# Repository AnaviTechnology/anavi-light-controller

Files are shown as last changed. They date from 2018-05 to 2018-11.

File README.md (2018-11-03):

# ANAVI Light Controller

ANAVI Light Controller is an open source hardware board for controlling 12V RGB LED strip powered by free and open source software. It features:

* Slot for RGB LED strip
* 12V input for the RGB LED strip
* Slots for up to 3 plug and play I2C sensors for temperature, barometric pressure, humidity and light
* UART (Universal asynchronous receiver/transmitter) pins for debugging

Open source software for ANAVI Light Controller written as an Arduino sketch is also available at [GitHub](https://github.com/AnaviTechnology/anavi-light-controller-sw).

# License

The project is released under the [Creative Commons Attribution-ShareAlike 4.0 International (CC BY-SA 4.0)](https://creativecommons.org/licenses/by-sa/4.0/).

Note: This is a human-readable summary of (and not a substitute for) the [license](https://creativecommons.org/licenses/by-sa/4.0/legalcode).

You are free to:

Share — copy and redistribute the material in any medium or format Adapt — remix, transform, and build upon the material for any purpose, even commercially. The licensor cannot revoke these freedoms as long as you follow the license terms. Under the following terms:

Attribution — You must give appropriate credit, provide a link to the license, and indicate if changes were made. You may do so in any reasonable manner, but not in any way that suggests the licensor endorses you or your use. ShareAlike — If you remix, transform, or build upon the material, you must distribute your contributions under the same license as the original. No additional restrictions — You may not apply legal terms or technological measures that legally restrict others from doing anything the license permits. Notices:

You do not have to comply with the license for elements of the material in the public domain or where your use is permitted by an applicable exception or limitation. No warranties are given. The license may not give you all of the permissions necessary for your intended use. For example, other rights such as publicity, privacy, or moral rights may limit how you use the material.

You will have to provide a link to the original creator of the project http://www.anavi.technology on any documentation or website.

Credit can be attributed through a link to the creator website: http://www.anavi.technology

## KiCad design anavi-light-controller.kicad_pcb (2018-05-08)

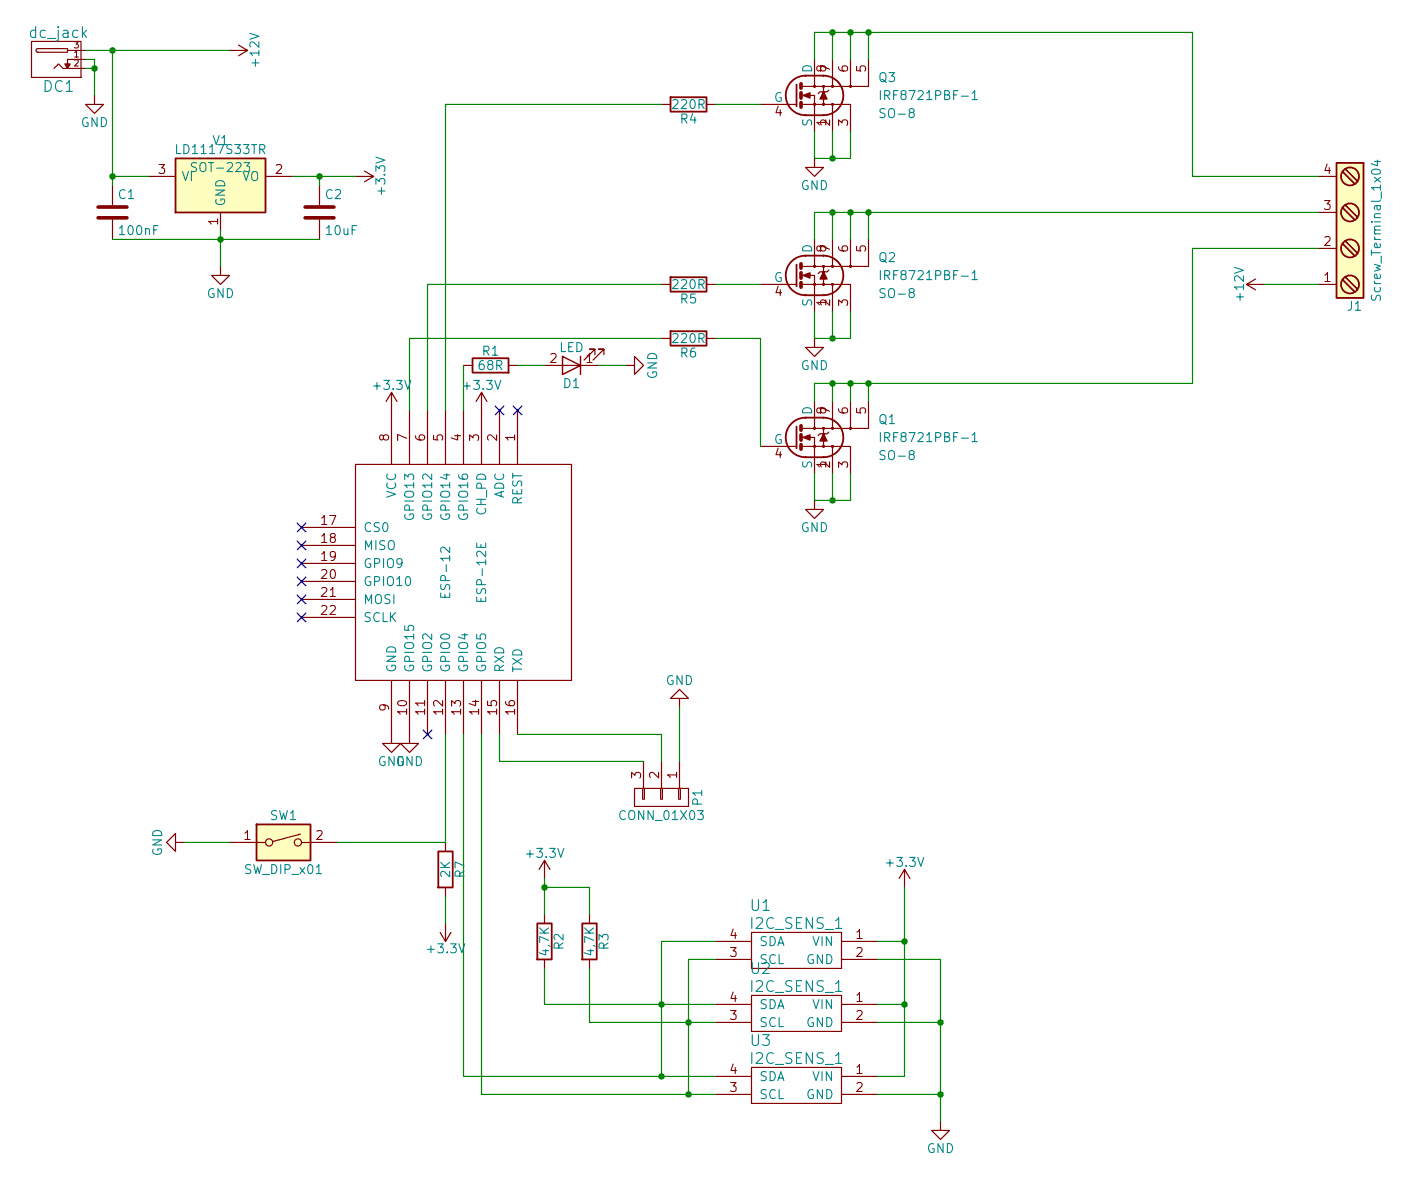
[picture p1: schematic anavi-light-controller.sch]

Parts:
C1: 100nF; C_0603_HandSoldering
C2: 10uF; C_0805_HandSoldering
D1: LED; LED_1206
DC1: dc_jack; dc_socket
ESP-12: ESP-12E; ESP-12E_SMD
J1: Screw_Terminal_1x04; TerminalBlock_Pheonix_MKDS1.5-4pol
P1: CONN_01X03; Pin_Header_Straight_1x03
Q1, Q2, Q3: IRF8721PBF-1; SO-8
R1: 68R; R_0603_HandSoldering
R2, R3: 4,7K; R_0603_HandSoldering
R4, R5, R6: 220R; R_0603_HandSoldering
R7: 2K; C_0603_HandSoldering
SW1: SW_DIP_x01; SW_PUSH_6mm_h4.3mm
U1, U2, U3: I2C_SENS_1; Pin_Header_Straight_1x04
V1: LD1117S33TR; SOT-223

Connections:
+3V3: C2.1, ESP-12.3 (CH_PD), ESP-12.8 (VCC), R2.1, R3.1, R7.2, U1.1 (VIN), U2.1 (VIN), U3.1 (VIN), V1.2 (VO)
+12V: C1.1, DC1.3, J1.1, V1.3 (VI)
GND: C1.2, C2.2, D1.1 (K), DC1.1, DC1.2, ESP-12.9 (GND), ESP-12.10 (GPIO15), P1.1, Q1.1 (S), Q1.2, Q1.3, Q2.1 (S), Q2.2, Q2.3, Q3.1 (S), Q3.2, Q3.3, SW1.1, U1.2 (GND), U2.2 (GND), U3.2 (GND), V1.1 (GND)
unnamed: D1.2 (A), R1.2
unnamed: ESP-12.4 (GPIO16), R1.1
unnamed: ESP-12.5 (GPIO14), R4.2
unnamed: ESP-12.6 (GPIO12), R5.2
unnamed: ESP-12.7 (GPIO13), R6.2
unnamed: ESP-12.12 (GPIO0), R7.1, SW1.2
unnamed: ESP-12.13 (GPIO4), R2.2, U1.4 (SDA), U2.4 (SDA), U3.4 (SDA)
unnamed: ESP-12.14 (GPIO5), R3.2, U1.3 (SCL), U2.3 (SCL), U3.3 (SCL)
unnamed: ESP-12.15 (RXD), P1.3
unnamed: ESP-12.16 (TXD), P1.2
unnamed: J1.2, Q1.5, Q1.6, Q1.7, Q1.8 (D)
unnamed: J1.3, Q2.5, Q2.6, Q2.7, Q2.8 (D)
unnamed: J1.4, Q3.5, Q3.6, Q3.7, Q3.8 (D)
unnamed: Q1.4 (G), R6.1
unnamed: Q2.4 (G), R5.1
unnamed: Q3.4 (G), R4.1

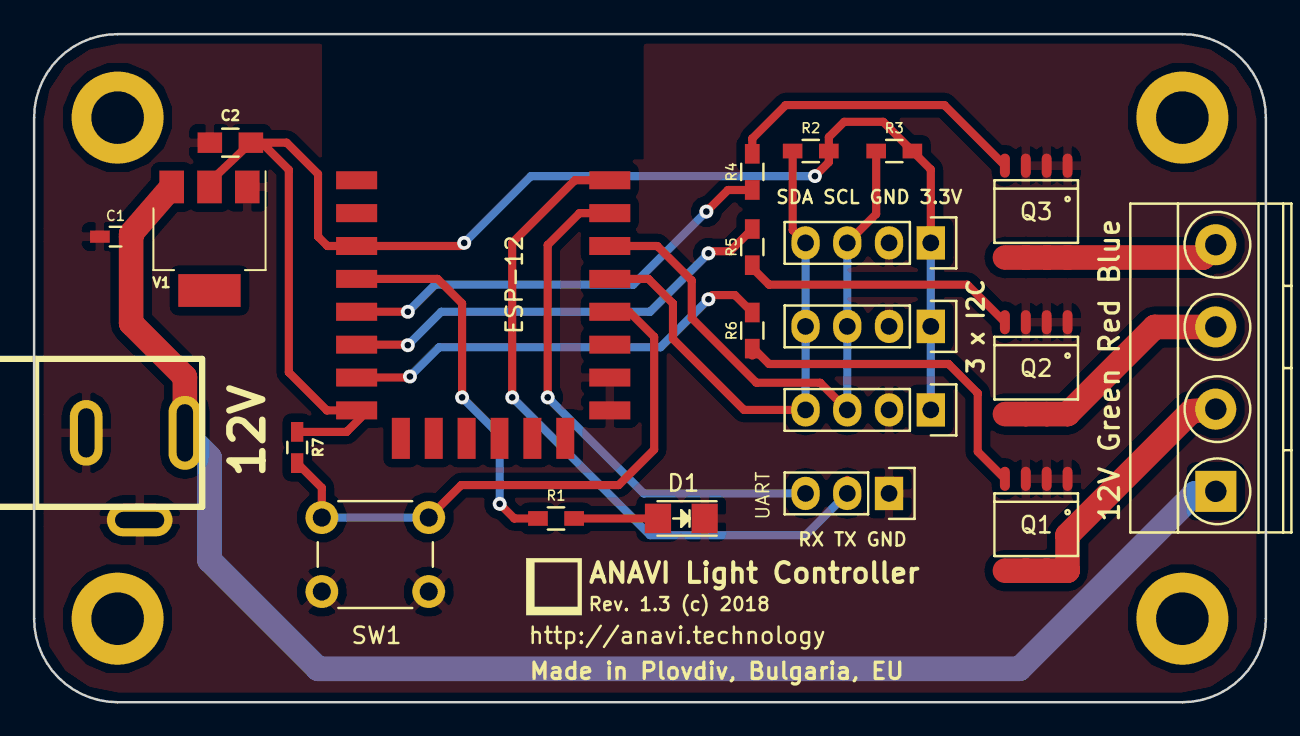
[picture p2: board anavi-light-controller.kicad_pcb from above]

Board: 2 copper layers, 74.9 x 40.6 mm, 22 parts (0 on the bottom side), 19 nets.

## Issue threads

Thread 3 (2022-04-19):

Temperature and humidity sensors stopped working

mircicd, 2022-04-19:
Hello

I did not find any official support channels so I'm putting my (most likely user-)issue here: I have been using the Light Controller for a good amount of time now without any problems. I've hooked up a few additional sensors to track temperature, humidity and light intensity: HTU21D, BH1750 and SHT31 (for which I have added support myself). All the sensors have worked flawlessly for more than a year.

I'm running the Light Controller in a Home Assistant Setup. The problem is that all of a sudden I stopped getting sensor data into my MQTT broker, for any of the sensors. I can still send commands to the Light Controller to control the lights, but it just won't send any sensor data. Of course I did several resets and flashed the original firmware but without success.

Is this a known issue or is there any way to debug to find out what the problem might be? I'm using Mosquitto and these are the only relevant logs I could find:
```
Tue Apr 19 18:54:15 2022: New connection from 192.168.1.27 on port 1883.
Tue Apr 19 18:54:15 2022: Client anavi-light-controller-4af09a0ea709ffdc47d2a9fc1cf81f9 has exceeded timeout, disconnecting.
Tue Apr 19 18:54:15 2022: Socket error on client anavi-light-controller-4af09a0ea709ffdc47d2a9fc1cf81f9, disconnecting.
Tue Apr 19 18:54:15 2022: New client connected from 192.168.1.27 as anavi-light-controller-4af09a0ea709ffdc47d2a9fc1cf81f9 (c1, k15, u'').
```

Any help is appreciated!

leon-anavi, 2022-04-20:
Hi @mircicd,

As an entirely open source project this is an appropriate place to report this type of issues.

Are the sensor modules still properly working as hardware and detected by their I2C addresses?

Have you tried flashing the latest version of original open source firmware?

Would you like to contribute your modifications for SHT31-D as a GitHub pull request to https://github.com/AnaviTechnology/anavi-light-controller-sw ?

Best regards,
Leon

mircicd, 2022-05-13:
Hi Leon

As per your suggestion I took out the sensors and tested them individually and one by one on a different device. Turned out that the SHT31 sensor was broken! And for some strange reason, leaving it connected to the Light Controller causes all sensor data to stop. After having removed only the broken sensor, I now get sensor readings again as expected. Thanks a lot for your push to the right direction.

I will gladly open a pull request to add SHT31-D support once I find some time to clean up and polish my code.

Best regards,
Dejan

Closed 2022-05-13.

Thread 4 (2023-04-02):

Quick question

Fizcko, 2023-04-02:
Hello,

Can this project support a 12v 3A input for a 10m RGB LED strip ?

I don't know if all electronics components can support up to 3A.

Thanks for the reply

leon-anavi, 2023-04-02:
Hi @Fizcko,

ANAVI Light Controller uses IRF8721PBF/IRF8721TRPBF MOSFET for each of the 3 channels for the RGB light. According to the datasheet the Continuous Drain Current of each is up to 14A: https://www.mouser.bg/ProductDetail/Infineon-IR/IRF8721TRPBF

The traces on the boards are 20mils so in practice it is about 2.5Amps per channel and 60mils for the 12V trace. Depending on your setup it is also possible to wire the 12V for the RGB LED strip directory to the power adapter (and skip using the 12V trace on the board). It is also to use a DC barrel jack male adapter to a screw terminal. These adapters are quite popular because they are widely used for CCTV and can be found from many resellers, for example Sparkfun offers them: https://www.sparkfun.com/products/10287

Fizcko, 2023-04-02:
@leon-anavi

I didn't buy anything I'm studying the technical feasibility for the moment.

Thanks for the reply

Closed 2023-04-02.

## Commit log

2017-08-10 anavi-light-controller: Initial version
    [anavi-light-controller.kicad_pcb, anavi-light-controller.sch]
2017-08-10 anavi-light-controller: Add labels
    [anavi-light-controller.kicad_pcb]
2017-08-10 anavi-light-controller.kicad_pcb: Rotate I2C
    [anavi-light-controller.kicad_pcb]
2017-08-10 anavi-light-controller.kicad_pcb: Increase tracks
    Increace 12V tracks and change the positions of
    the capacitors.
    [anavi-light-controller.kicad_pcb]
2017-08-10 anavi-light-controller.kicad_pcb: no vias
    [anavi-light-controller.kicad_pcb]
2017-08-10 anavi-light-controller.kicad_pcb: reduce
    Reduce width of the PCB and change the mounting holes.
    [anavi-light-controller.kicad_pcb]
2017-09-12 Change LDO voltage regulator
    Use LD1117S33TR as LDO voltage regulator to drop
    from 12V to 3.3V and to power the ESP8266 module.
    [anavi-light-controller.kicad_pcb, anavi-light-controller.sch]
2017-09-12 Enable ESP-12; Fix the button and LED
    Enable ESP-12 by connecting GPIO5 to GND and CH_PD
    to 3.3V. Add 2K resistor to GPIO0 to fix the button
    and move the alarm LED on the other side.
    [anavi-light-controller.kicad_pcb, anavi-light-controller.sch]
2017-09-13 kicad_pcb: Adjust positions of components
    Adjust the positions of the red LED and the button.
    [anavi-light-controller.kicad_pcb]
2017-09-13 kicad_pcb: Increase font of the product name
    [anavi-light-controller.kicad_pcb]
2018-03-31 rev1.2: Use SMD footprint for ESP-12E
    Use SMD footprint for ESP-12E to simplify the
    assembly, updated product version and routing.
    [anavi-light-controller.kicad_pcb, anavi-light-controller.sch]
2018-04-04 anavi-light-controller.kicad_pcb: Keepout zones
    Add keepout zones below the ESP-12 antenna.
    [anavi-light-controller.kicad_pcb]
2018-04-15 README.md: CC BY-SA 4.0
    Switch license to CC BY-SA 4.0 to comply with
    the requirements for open source hardware.
2018-04-26 anavi-light-controller.kicad_pcb: Fix ESP12 wiring
    Fix the wiring of ESP12 as two pins must be
    connected to 3.3V in order to work properly.
    [anavi-light-controller.kicad_pcb]
2018-05-07 ESP-12E_SMD.kicad_mod: Remove silkscreen from pads
    Remove white silkscreen line from pads.
    [anavi-light-controller.kicad_pcb]
2018-05-07 anavi-light-controller.kicad_pcb: Rotate ESP-12E
    Rotate ESP8266 model ESP-12E to 90 degrees to
    improve the signal strenght of the WiFi antenna
    and increase the revision to 1.3.
    Huge thanks for the suggested improvements to Jon
    Raymond (twitter: @Jon_Raymond_) and John Lee
    (twitter: @EspressifSystem).
    [anavi-light-controller.kicad_pcb]
2018-05-08 anavi-light-controller-brd.svg: Assembly
    Add image with assembly instructions.
    [anavi-light-controller.kicad_pcb]
2018-05-08 anavi-light-controller.kicad_pcb: Improve routing
    Improve the 3.3V wiring.
    [anavi-light-controller.kicad_pcb]

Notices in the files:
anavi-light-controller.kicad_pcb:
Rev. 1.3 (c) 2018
